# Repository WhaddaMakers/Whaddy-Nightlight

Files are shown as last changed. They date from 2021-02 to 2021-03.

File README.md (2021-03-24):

# Whaddy Nightlight

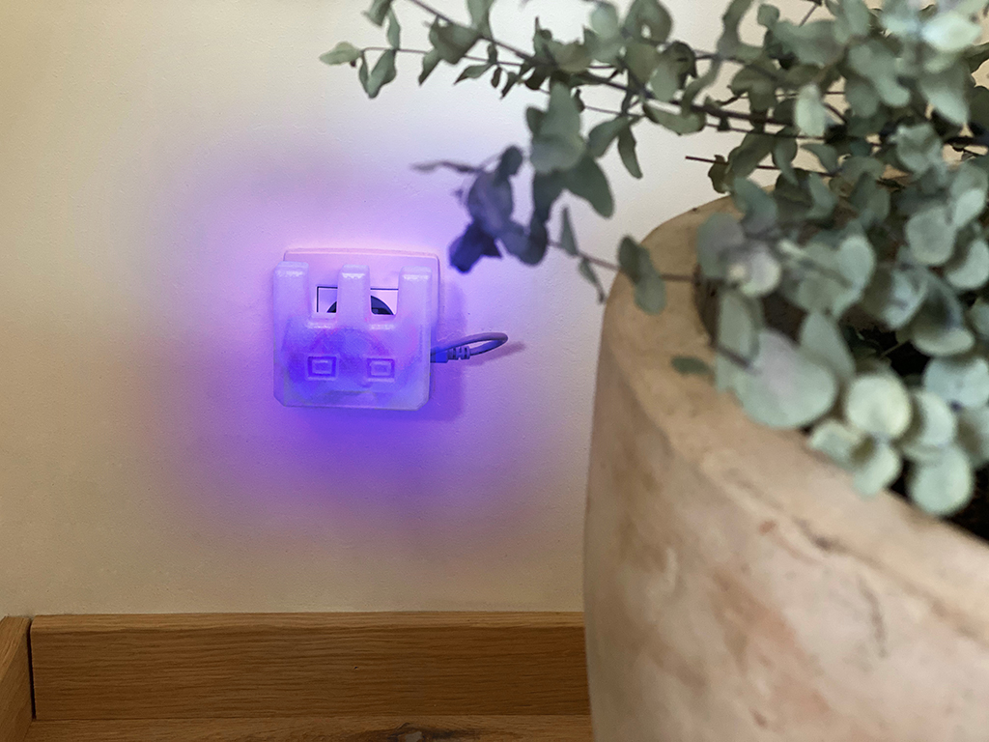
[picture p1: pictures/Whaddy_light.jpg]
demo


Make a cool nightlight in the shape of Whadda's very own mascot, Whaddy! This design will fit onto any phone charger in the EU.

## Project description - How Does it work?

### What can this project do?
This project uses a digital light sensor to measure the ambient light. When a certain light value is reached, the 2 SMD RGB LEDs will turn on and give your room or hallway a purple glow!
The enclosure is designed for 3D printing and has the shape of our mascot!
The parts are also designed to have a snap fit connection for the electronic modules and to close it. This way, you don't need any screws. 
The nightlight is supported by a bracket which you also need to 3D print, and is designed for most EU mobile phone chargers or small USB adaptors.

### Level of difficulty: intermediate

## MATERIALS

### Ingredients:
* Arduino Nano or equivalent like the [Whadda Atmega328 Nano Development Board (WPB102)](https://whadda.com/product/atmega328-development-board-wpb102/)
* [BH1750 dgital light intensity sensor module](https://whadda.com/product/bh1750-digital-light-intensity-sensor-module-vma341/)
* [Arduino® compatible 3 colour RGB SMD LED module (2 pcs)](https://whadda.com/product/arduino-compatible-3-colour-rgb-smd-led-module-2-pcs-vma318/)
* [1.75 mm (1/16″) PLA filament - natural – 750 G](https://whadda.com/product/1-75-mm-1-16-pla-filament-natural-750-g-pla175n07/)
* soft electrical wires
* any USB A cable (an old one is good enough but it has to work)
* standard EU phone charger/adaptor

### Tools:
* PC with [Arduino IDE](https://www.arduino.cc/en/Main/Software) installed
* soldering iron
* solder
* stripping pliers
* cutting pliers
* shrink tubes
* heat gun of hair dryer
* 3D printer

## 3D printing the NightLight:

The Nightlight consist out of 3 3D printed parts:
* Nightlight Top  (Whaddy_Nightlight_TOP.stl)
* Nightlight Bottom (Whaddy_Nightlight_BOTTOM.stl)
* Nightlight Bracket (Charger_Holder.stl)

Find all the .stl files for the case of this project on our Thingiverse account: https://www.thingiverse.com/thing:4804543

There are no supports needed. Be sure to 3D print the Nightlight Top and Bottom in a transparent filament. Otherwise, you won`t be able to see the LEDs inside. 
Also, be sure to print it with 100% infill to get the best result.

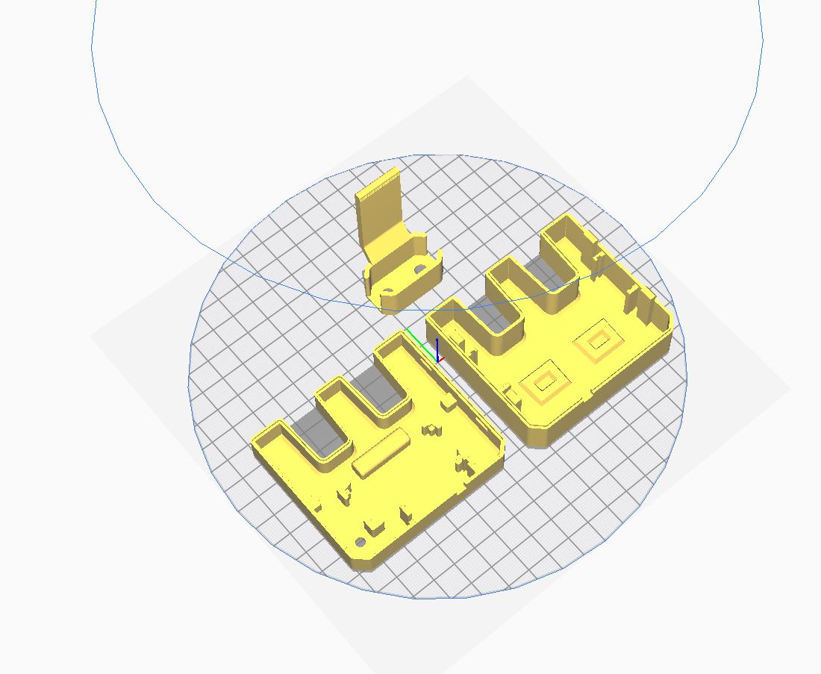
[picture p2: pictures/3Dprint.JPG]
Cura


## Programming the development board

### Dev board: Arduino Nano (compatible)

### Processor: ATMega328P

### Code language: Arduino

### Difficulty: Medium

### Preparations:
#### Installing Arduino Libraries

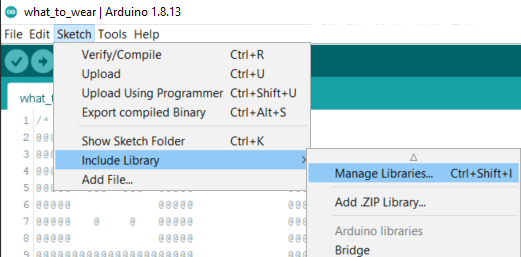
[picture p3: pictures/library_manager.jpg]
Arduino Library manager


Use the Arduino library manager (```Sketch > Include Library > Manage Libraries...```) to install the following libraries:

* [hp_BH1750(by Starmbi)](https://github.com/Starmbi/hp_BH1750)

#### Checking the Arduino sketch

1) Open the ```Whaddy_Nighlight.ino``` Arduino Sketch
2) Select the ```Arduino Nano``` board form the board's menu by going to ```Tools > Board > Arduino AVR Boards > Arduino Nano```
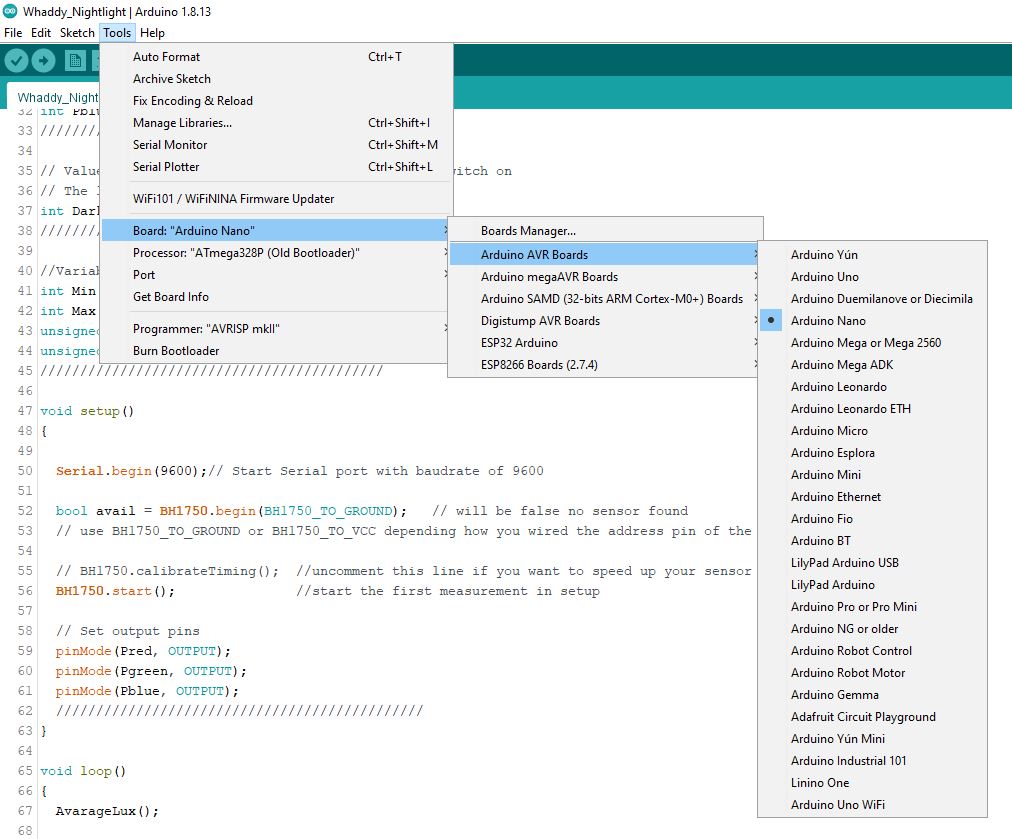
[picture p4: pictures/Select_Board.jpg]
boardselect

3) Select the ```ATmega328P (Old Bootloader)``` board form the board's menu by going to ```Tools > Processor >  > ATmega328P (Old Bootloader)```
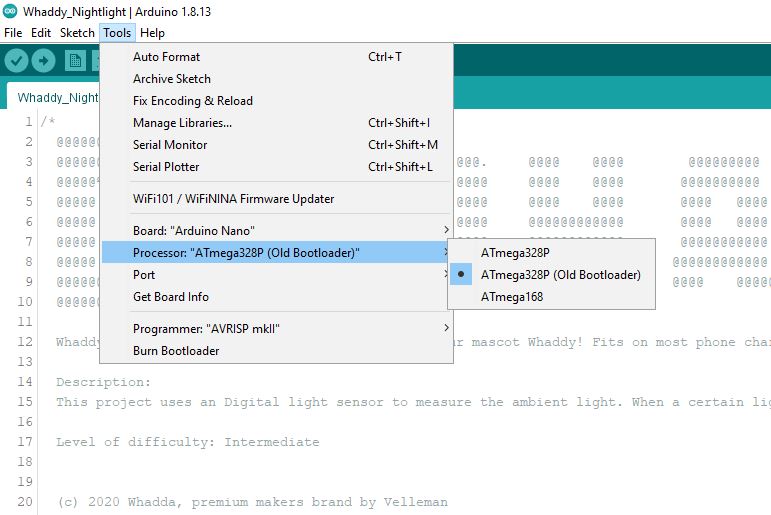
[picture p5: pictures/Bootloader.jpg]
Bootloader

4) Check if the Arduino sketch compiles correctly by hitting the ```Verify``` button (checkmark button left of the upload button). If everything is installed correctly, no errors should pop-up and the compilation process should finish with the final message ```Done compiling```. If this process fails, please check if you installed all necessary libraries and selected the correct board.

## Prepping the connections
### Connection table light sensor
| BH1750 digital light intensity sensor | Arduino Nano |
|:---:|:---:|
| G | GND |
| V | 5V |
| SDA | A4 |
| SCL | A5 |

### Connection table SMD RGB LEDs 
|3 COLOUR RGB SMD LED MODULE | Arduino Nano |
|:---:|:---:|
| - | GND |
| G | A2 |
| R | A1 |
| B | A0 |

## Running the code!

Almost done with the coding part. After this we can start installing the electronics in the 3D printed case.

### Setting the light value

As mentioned earlier, the RGB LEDs will turn on when it gets dark. The value corresponds to the ambient ligt that the senor is measuring (LUX). 
So 0 = DARK
300 = OFFICE LIGHT
100 000 = SUNLIGHT :) 
We`ve set the value so that it turns on at twilight (10).
Changing the value can be done here:

```Cpp
// Value to determe at wich value the LEDs should switch on
// The lower the value, the darker 
int Dark = 10;
/////////////////////////////////////////
```

### Changing the color of the RGB LEDs 

You can change the color of the nightlight to whatever you want by changing the setColor value(R, G, B) format. We`ve set it to Whadda purple. 

```Cpp
  if (Alux < Dark) {      // When Avarage Lux measurement is lower then....
    setColor(210, 0, 210); // Set color to Purple (RGB)
  }
  ```
### Uploading and checking the program
You are now ready to upload the code! Hit the upload button and wait until the program is compiled and uploaded. The nightlight should turn on when you cover the light sensor with your hand. If you're encountering any issue, check the serial monitor to see if the board was able to give correct readings from the B1750 dgital light intensity sensor.

## Soldering and assembling the electronics
## Overview of the ingredients

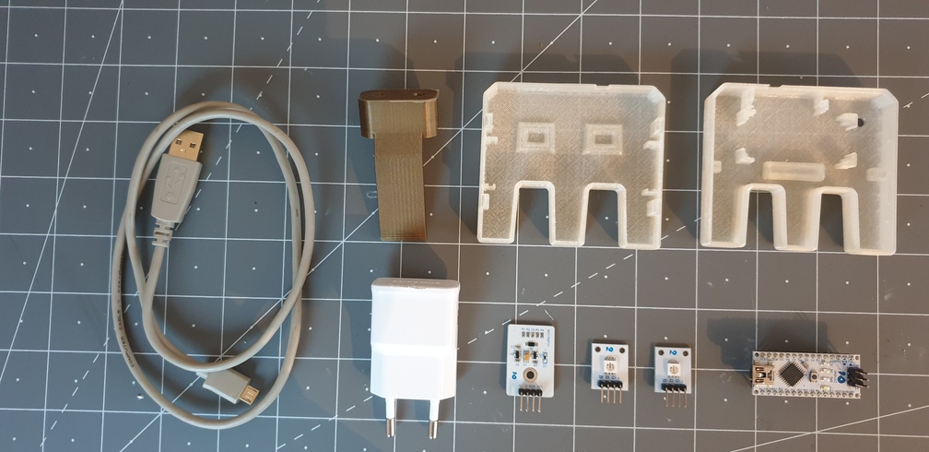
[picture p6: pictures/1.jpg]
INGREDIENTS


## Overview of the Tools
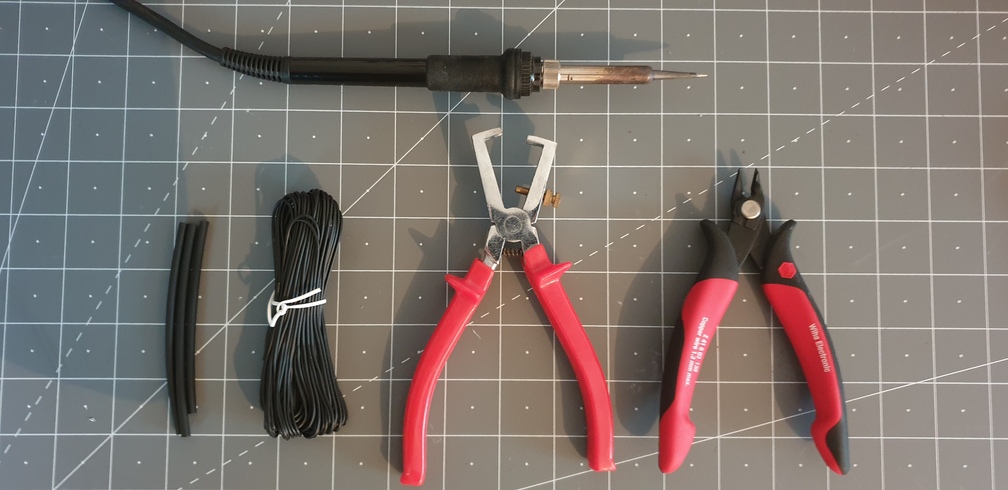
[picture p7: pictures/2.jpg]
TOOLS


Step 1: Cut off or desolder the ICSP pins from the Arduino Nano. We do this to save some space in the 3D printed case.
CUT OFF

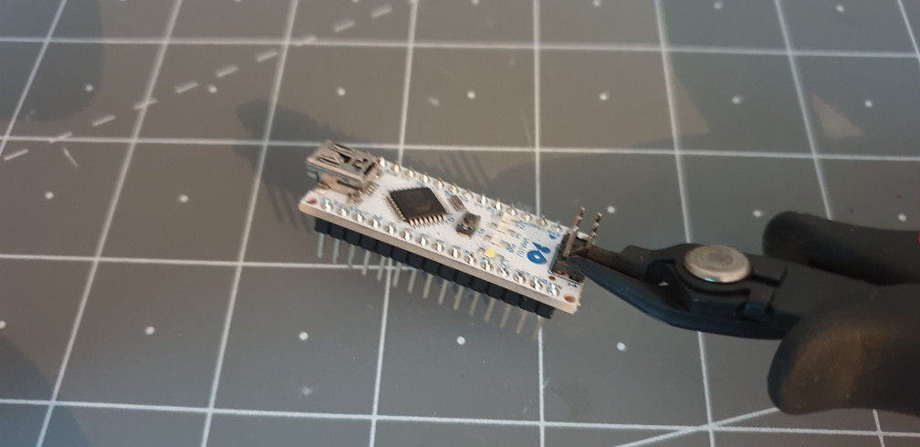
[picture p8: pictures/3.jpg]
CutOff


DESOLDER

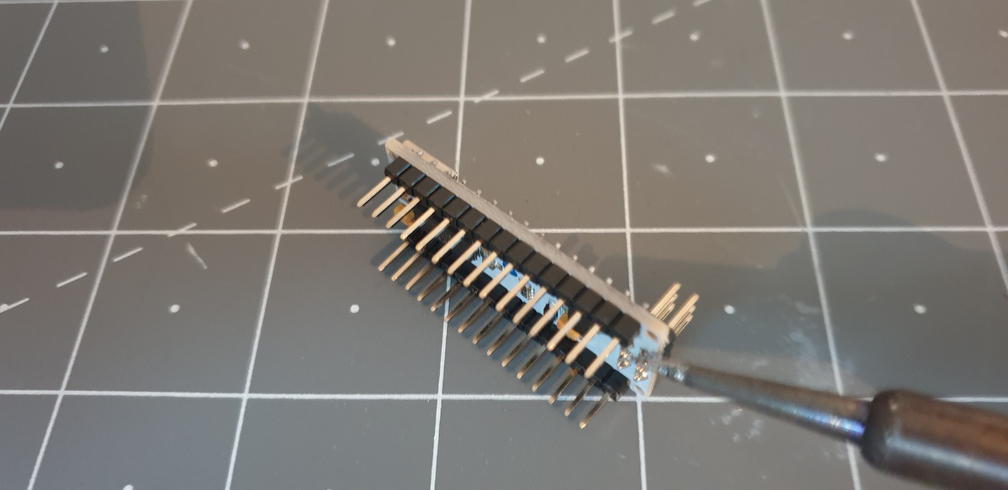
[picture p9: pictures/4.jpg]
Desolder


Step 2: Place the Arduino Nano into the provided place at the bottom of the case from the Nightlight, as shown in the picture below.

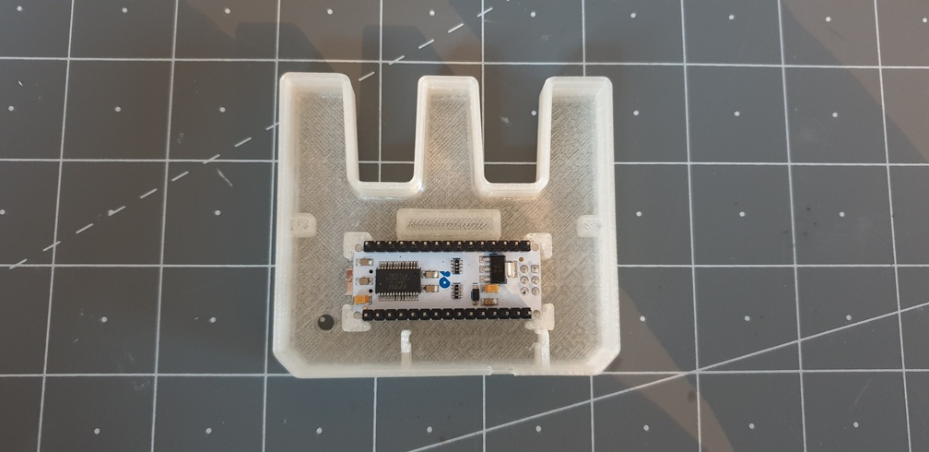
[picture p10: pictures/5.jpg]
ArduinoNano


Step 3: Solder 4 wires to the pins of the BH1750 digital light intensity sensor.

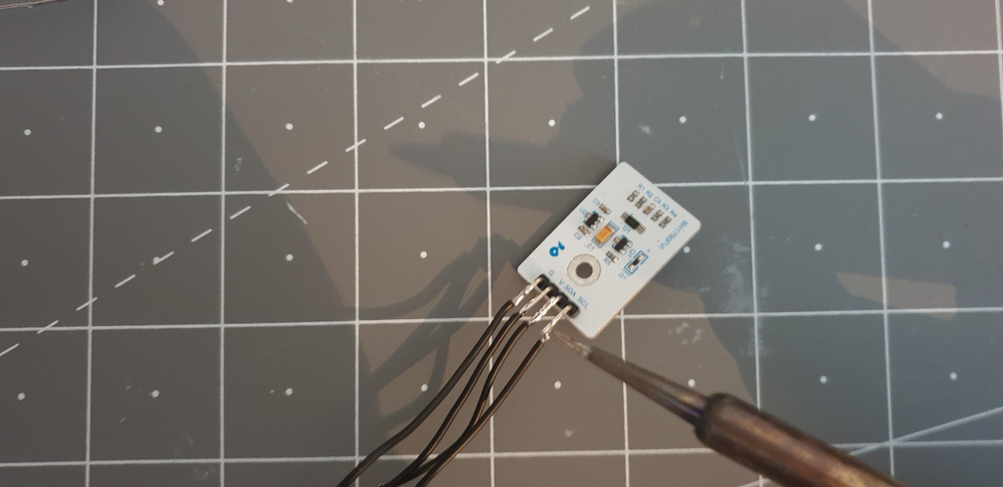
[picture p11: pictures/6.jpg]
LightSens


 Finish off the connections by putting heatshrinks around them.

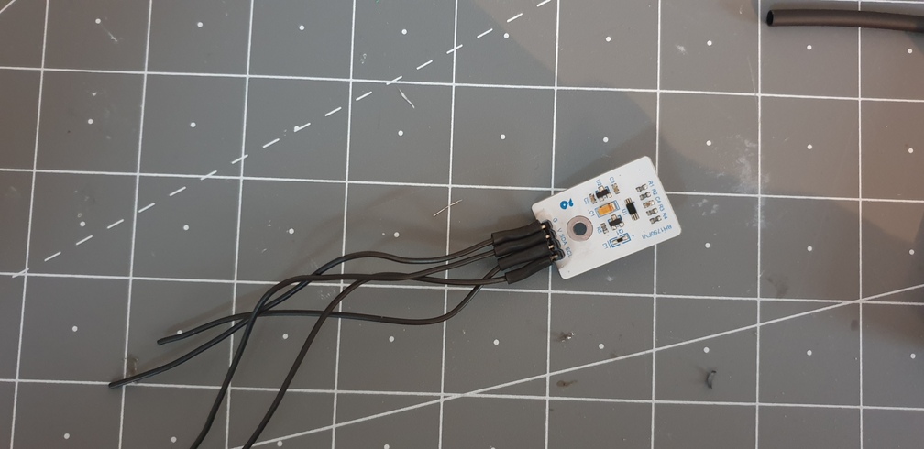
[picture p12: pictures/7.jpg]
LightSensHeat


Step 4: Place the BH1750 digital light intensity sensor in the provided place at the bottom of the case from the Nightlight.

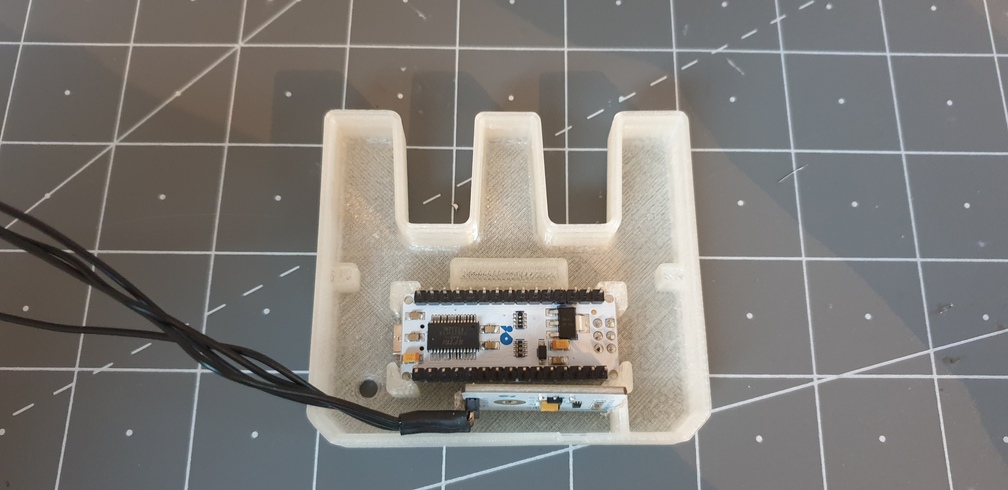
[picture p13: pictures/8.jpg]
LightSensCase


Step 5: Measure the aprox length of the cables from the light sensor to the Arduino Nano pins (See connection diagram), and cut them off. 

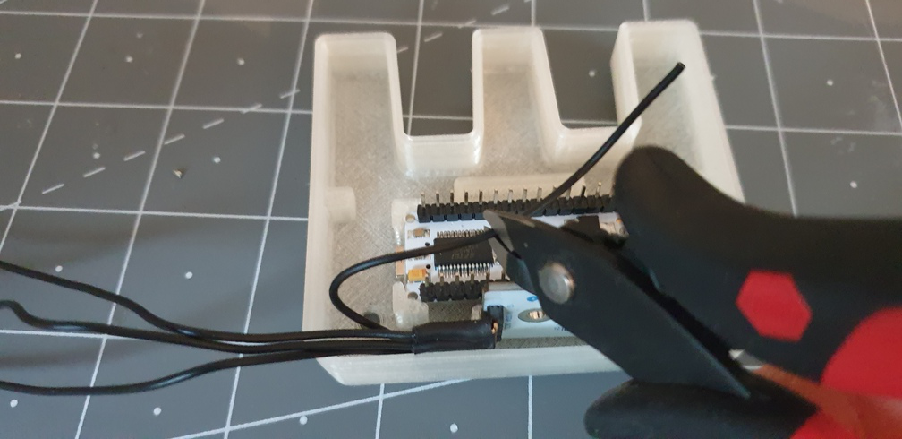
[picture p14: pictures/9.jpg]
LightSensWires


Step 6: Remove the Arduino and light sensor from the case. Solder the wires according the connection diagram. Don't forget to put heatshrinks onto the connections!!  DON'T SOLDER THE 5V YET, WE WILL DO THIS LATER ON.

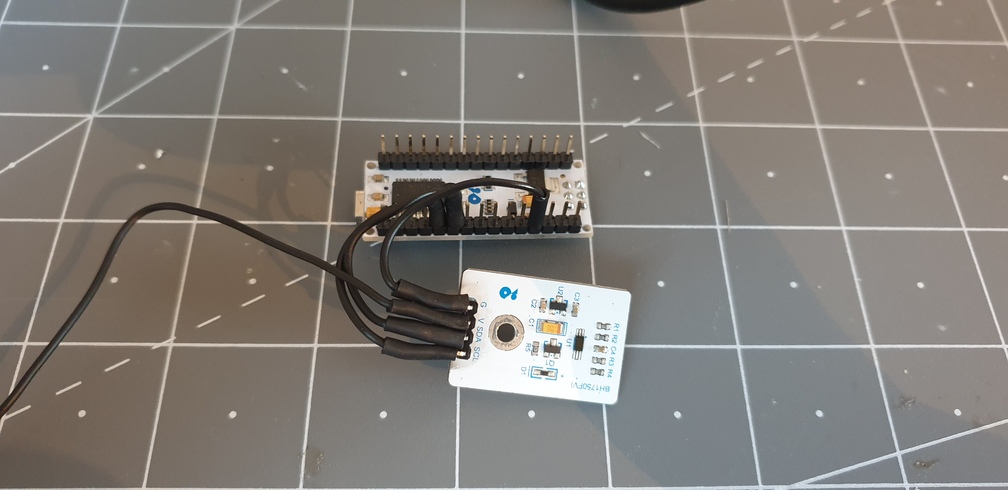
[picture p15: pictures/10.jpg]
LightSensSolder


Step 7: Solder wires to the pins of the SMD RGB LEDs modules. Don't forget to finsh the connections off with heatshrinks!

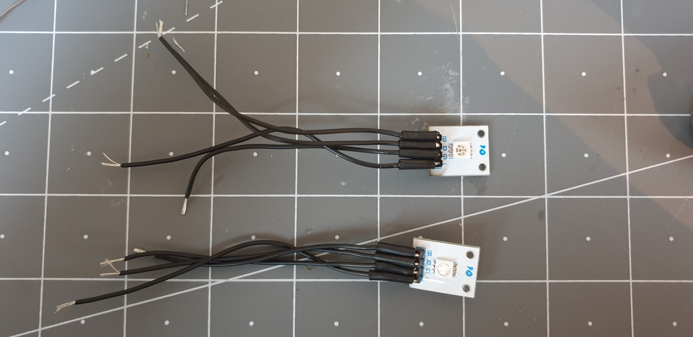
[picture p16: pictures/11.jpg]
LedsWires


Step 8: The Leds will be mounted in the TOP part of the nightlight. insert them in the provided place and. Then bring the wires from the 2 LED modules together (color by color) and cut them off as shown in the picture below (not too short, otherwise the assembly will be difficult). Again, do not forget the heatshrinks :).

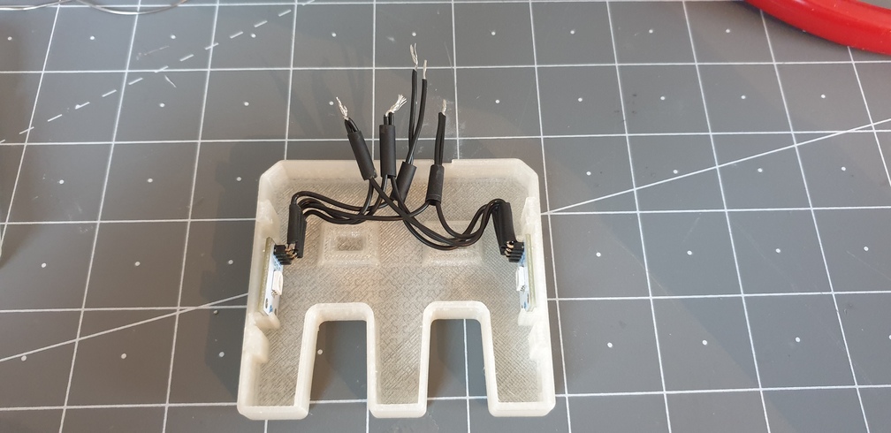
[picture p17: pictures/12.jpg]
LEDsWireLenght


Step 9: Start soldering the 2 SMD RGB led modules to the Arduino Nano according the connection diagram. DON'T SOLDER THE GND YET, WE WILL DO THIS LATER ON.

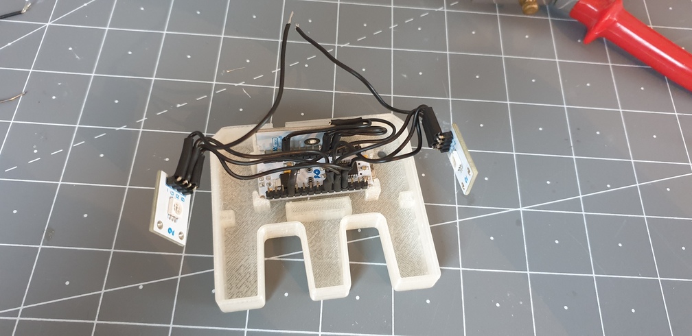
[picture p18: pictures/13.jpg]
LEDsSolder


The assembly should look something like this by now:

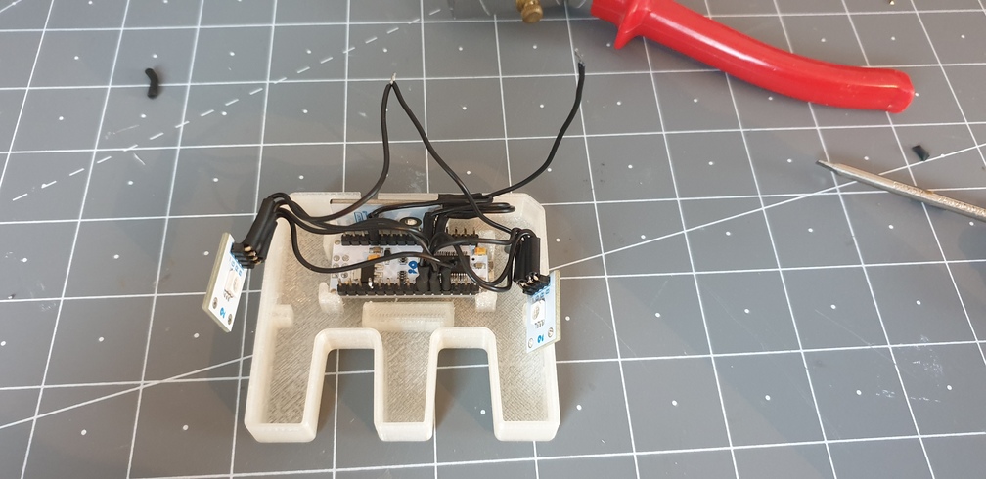
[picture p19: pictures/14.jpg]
Assembly


Step 10: Cut off the USB A cable (approx. 25cm) and strip it (approx. 7.5cm).

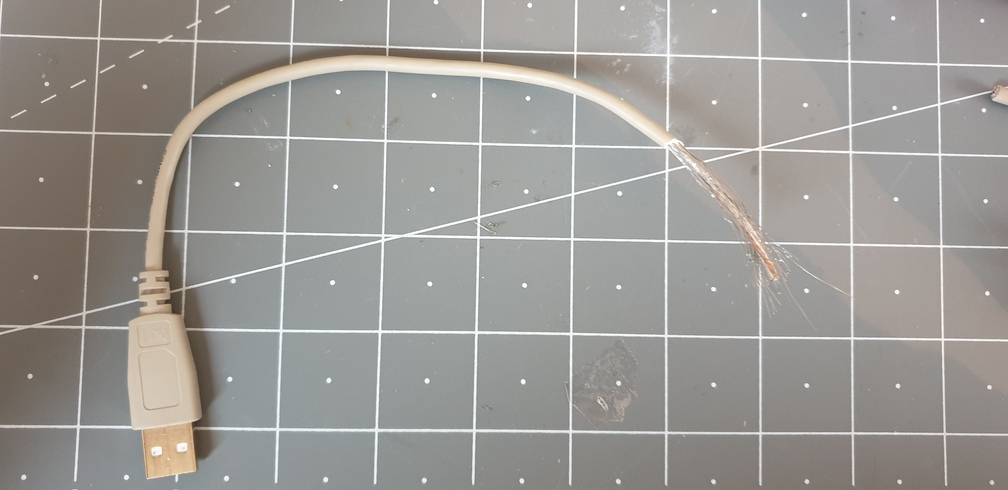
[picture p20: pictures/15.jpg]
USBcut


Step 11: Cut away the excess shielding and wires until you only have the + and - wires.

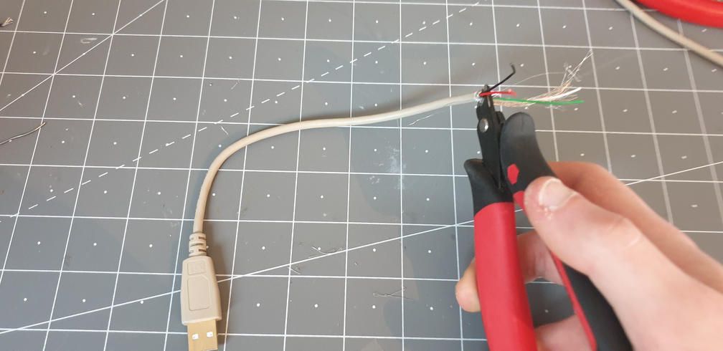
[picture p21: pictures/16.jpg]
USBstrip


 Then strip and solder the ends of these wires.

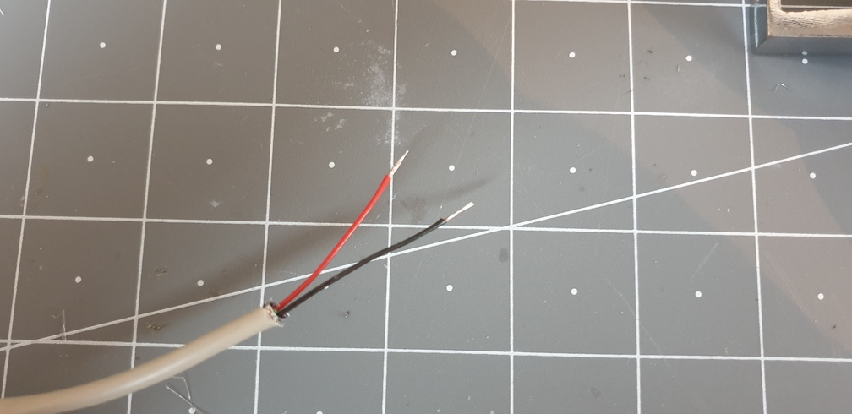
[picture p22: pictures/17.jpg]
USBstripends


Step 12: Feed the + and - wires trough the hole of the bottom part form the Nightlight.

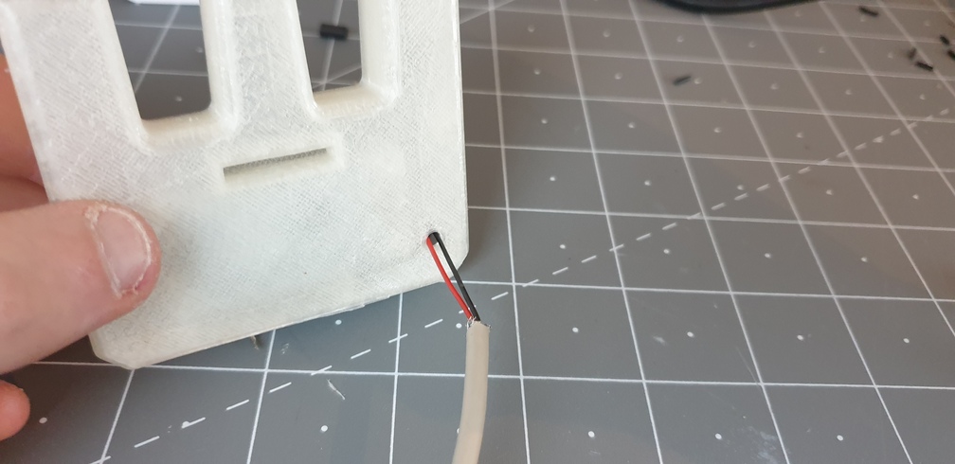
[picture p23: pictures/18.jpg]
USBfeed


Step 13: Solder the + wire from the USB cable and the 5V wire from the light sensor the the 5V pin of the Arduino Nano.

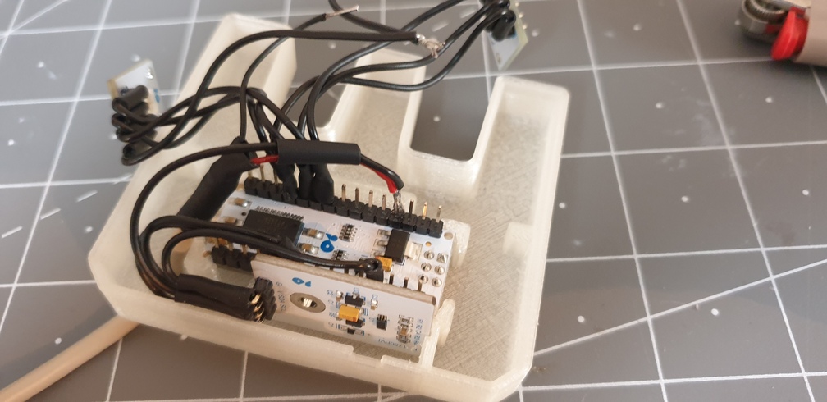
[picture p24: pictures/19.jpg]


Step 14: Solder the - from the USB cable and the - wires from RGB SMD LED modules to the GND pin of the Arduino Nano.

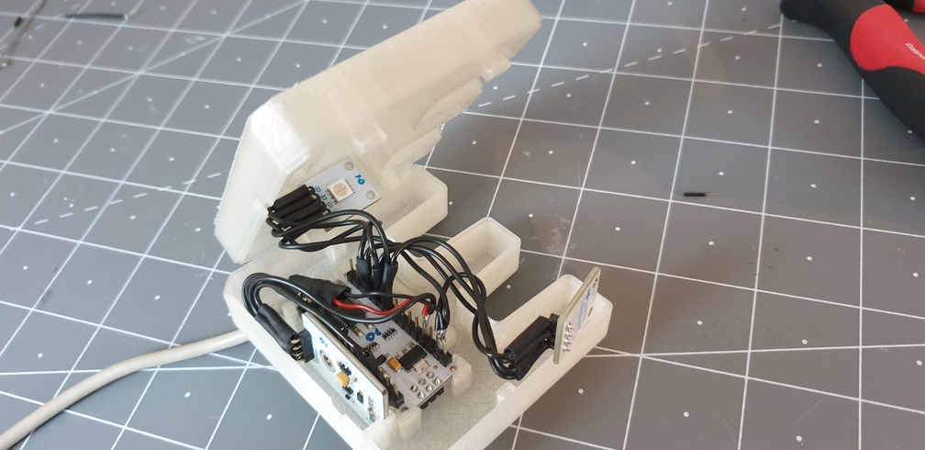
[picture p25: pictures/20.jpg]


Step 15: Slide the 2 LED modules into the provided place of TOP part from the Nightlight.

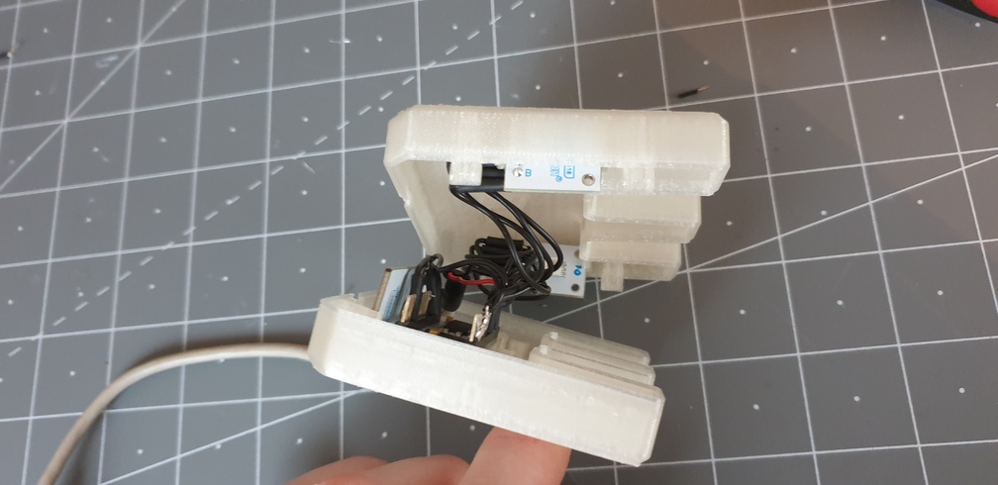
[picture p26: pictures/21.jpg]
LEdslide


Step 16: Now close the Nightlight TOP and BOTTOM half. The design uses a snap fit, so no need for screws!

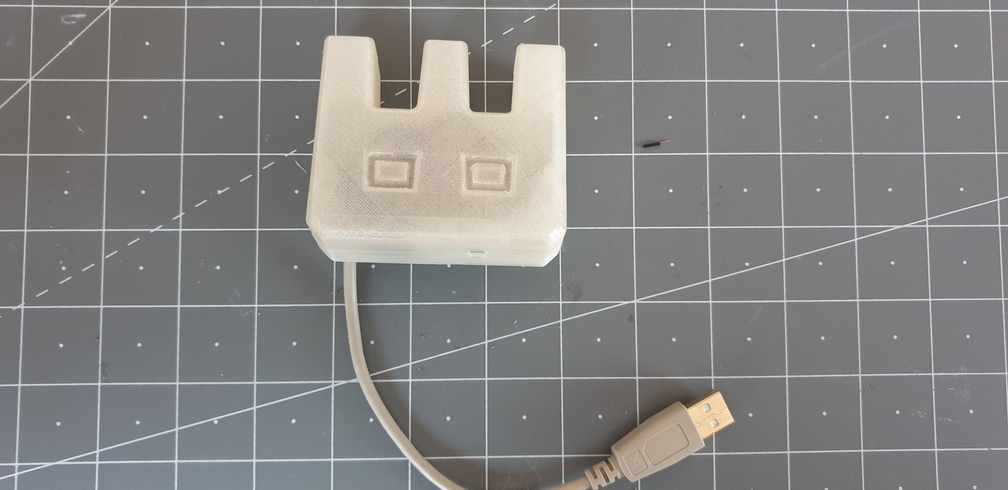
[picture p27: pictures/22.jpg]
CloseAssembly


Step 17: The next step is to mount the bracket on the charger, as shown in the picture below.

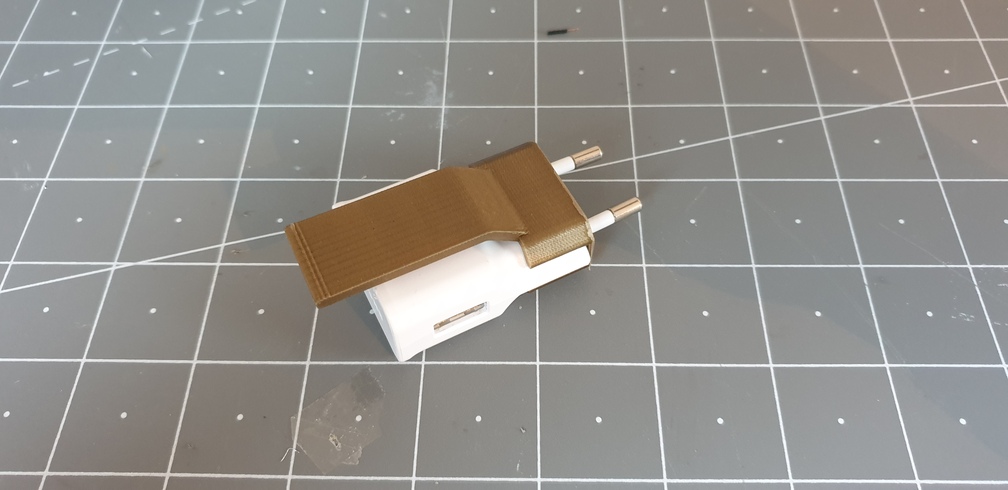
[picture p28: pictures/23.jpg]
Bracketmount


Step 18: Click the bracket into the slot of the BOTTOM part of the Nightlight. BE CAREFULL, DO NOTT BREAK THE BRACKET (it is a fairly tight fitting).

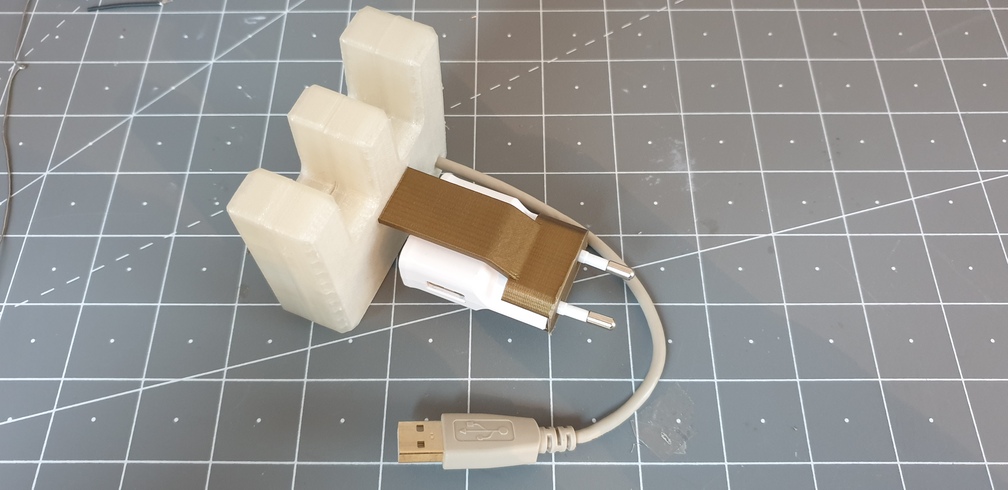
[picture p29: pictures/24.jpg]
Bracketmount2


Step 19: WOOHOOO, Last step. Plug the USB A into the Charger. 

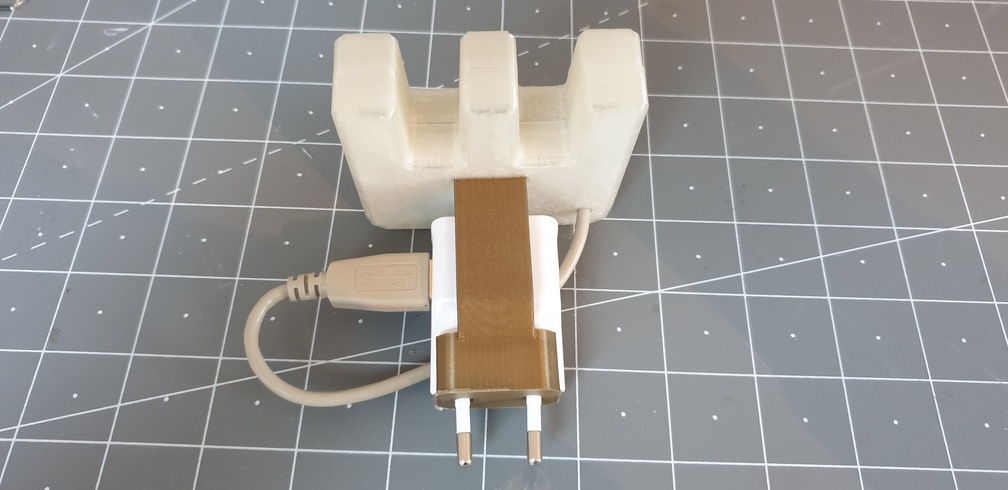
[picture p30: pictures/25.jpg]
USBplug


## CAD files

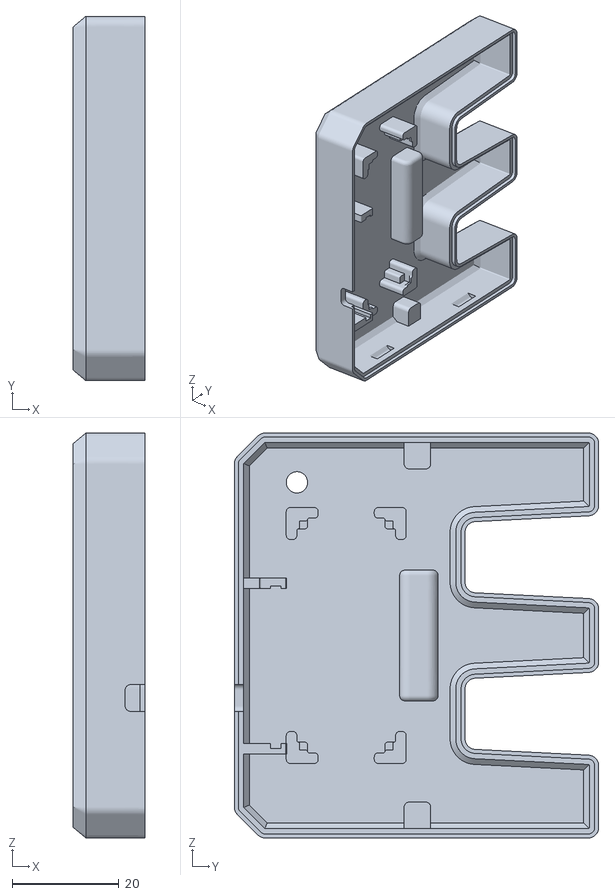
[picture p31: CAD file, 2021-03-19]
3D designs/Whaddy_Nightlight_BOTTOM.stl
13.4 x 68.3 x 75.9

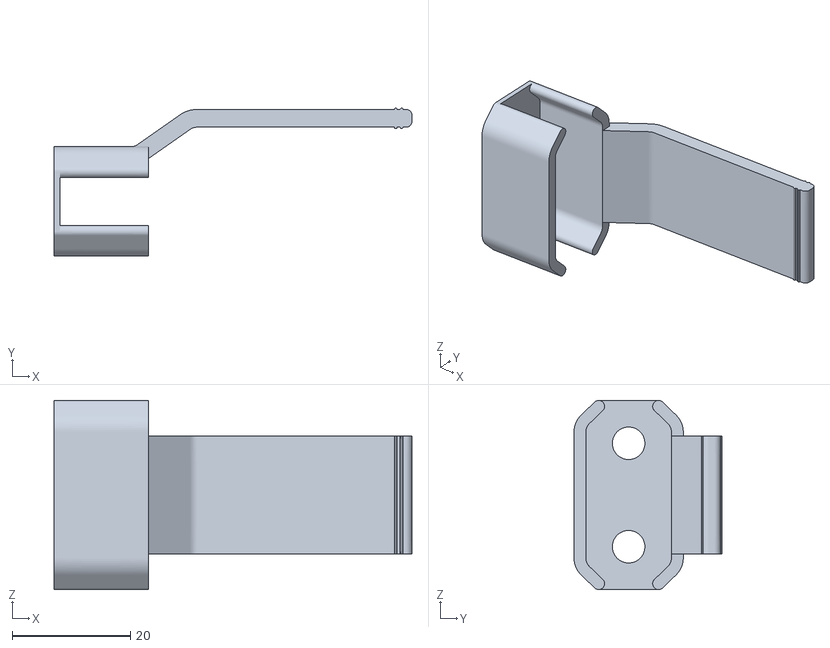
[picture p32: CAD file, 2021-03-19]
3D designs/ChargerHolder.stl
60.6 x 25.1 x 32.0

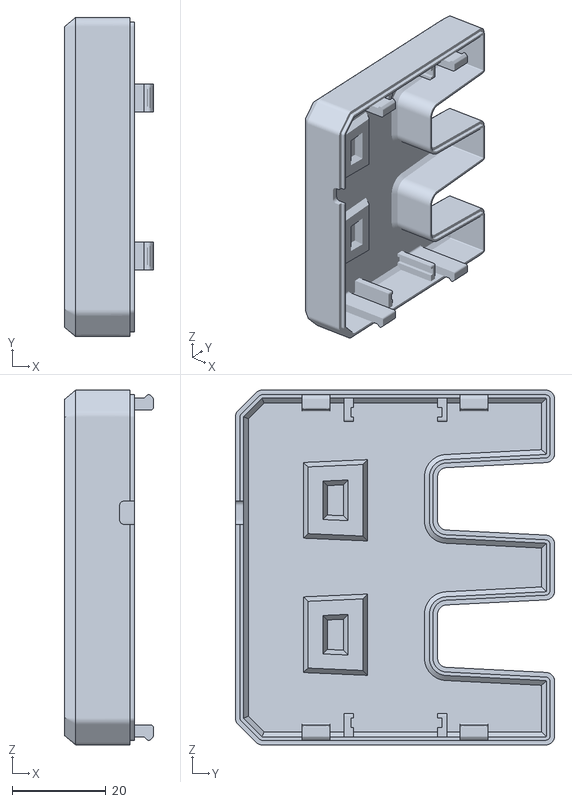
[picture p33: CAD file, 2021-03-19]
3D designs/Whaddy_Nightlight_TOP.stl
19.0 x 68.3 x 75.9

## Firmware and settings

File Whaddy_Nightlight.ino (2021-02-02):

/*
  @@@@@@@@@@@@@@@@@@@@@@
  @@@@@@@@@@@@@@@@@@@@@@             @@@.    @@@    @@@.     @@@@    @@@@        @@@@@@@@@        @@@@@@@@@@@@@.     .@@@@@@@@@@@@@        @@@@@@@@@
  @@@@@%%@@@%%@@@%%@@@@@             @@@@    @@@    @@@@     @@@@    @@@@       @@@@@@@@@@        @@@@@@@@@@@@@@     @@@@@@@@@@@@@@        @@@@@@@@@
  @@@@@  @@@  @@@  @@@@@             @@@@    @@@    @@@@     @@@@    @@@@       @@@@   @@@@        @@@@@   @@@@@       @@@@@   @@@@       @@@@   @@@@
  @@@@@            @@@@@             @@@@   @@@@    @@@@     @@@@@@@@@@@@       @@@@   @@@@        @@@@@   @@@@@       @@@@@   @@@@       @@@@   @@@@
  @@@@@   @    @   @@@@@             @@@@   @@@@    @@@@     @@@@@@@@@@@@       @@@@@@@@@@@        @@@@@   @@@@@       @@@@@   @@@@       @@@@@@@@@@@
  @@@@@            @@@@@             @@@@###@@@@@##@@@@@     @@@@    @@@@      @@@@@@@@@@@@       #@@@@@###@@@@@     ##@@@@@###@@@@       @@@@@@@@@@@
  @@@@@@@@@@@@@@@@@@@@@@             @@@@@@@@@@@@@@@@@@@     @@@@    @@@@      @@@@    @@@@@      @@@@@@@@@@@@@@     @@@@@@@@@@@@@@      @@@@     @@@@
  @@@@@@@@@@@@@@@@@@@@@@

  Whaddy Nightlight, a nightlight in the shape of our mascot Whaddy! Fits on most phone charger in the EU

  Description:
  This project uses an Digital light sensor to measure the ambient light. When a certain light value is reached, the 2 SMD RGB leds will turn on and give your room a purple shine!

  Level of difficulty: Intermediate


  (c) 2020 Whadda, premium makers brand by Velleman
*/

// Include necessary libraries
#include <Arduino.h>
#include <hp_BH1750.h>  //for help look at: https://github.com/Starmbi/hp_BH1750/wiki
hp_BH1750 BH1750;       //create the sensor object
//////////////////////////////////////

//Define pins for the SMD RGB LEDs
int Pred = A1;
int Pgreen = A2;
int Pblue = A0;
////////////////////////////////////////

// Value to determe at wich value the LEDs should switch on
// The lower the value,the darker 
int Dark = 10;
/////////////////////////////////////////

//Variables to calculate the light intensity value
int Min = 1023;
int Max = 0;
unsigned long Sum = 0;
unsigned long Alux;
///////////////////////////////////////////

void setup()
{

  Serial.begin(9600);// Start Serial port with baudrate of 9600

  bool avail = BH1750.begin(BH1750_TO_GROUND);   // will be false no sensor found
  // use BH1750_TO_GROUND or BH1750_TO_VCC depending how you wired the address pin of the sensor.

  // BH1750.calibrateTiming();  //uncomment this line if you want to speed up your sensor
  BH1750.start();               //start the first measurement in setup
  
  // Set output pins
  pinMode(Pred, OUTPUT);
  pinMode(Pgreen, OUTPUT);
  pinMode(Pblue, OUTPUT);
  //////////////////////////////////////////////
}

void loop()
{
  AvarageLux();

  if (Alux < Dark) {      // When Avarage Lux measurement is lower then....
    setColor(210, 0, 210); // Set color to Purple (RGB)
  }
  else if (Alux > Dark) { // When Avarage Lux measurement is Higher then....
    setColor(0, 0, 0);    // STurn LEDs off
  }

}

void setColor(int red, int green, int blue)
{
  analogWrite(Pred, red);
  analogWrite(Pgreen, green);
  analogWrite(Pblue, blue);
}

//Function to calculate the avarege lux from 10 readings
void AvarageLux()
{
  for  (int i = 0; i < 10; i++)
  {
    float lux = BH1750.getLux();
    BH1750.start();
    Sum = Sum + lux;

    if (lux < Min)
      Min = lux;

    if (lux > Max)
      Max = lux;
  }
  Alux = (Sum / 10);
  Serial.print (" Average = ");
  Serial.println (Alux);

}
